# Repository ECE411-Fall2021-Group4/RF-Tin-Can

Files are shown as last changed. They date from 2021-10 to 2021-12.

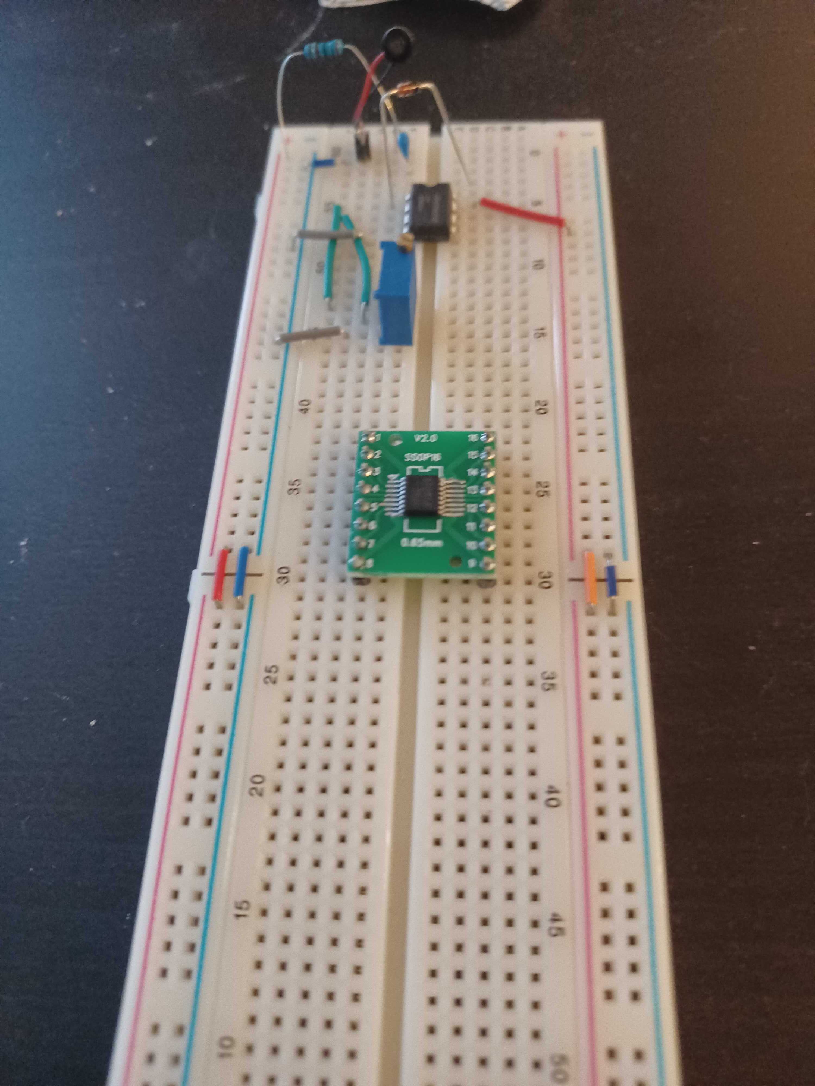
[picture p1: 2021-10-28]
images/Breadboard prototype.jpg

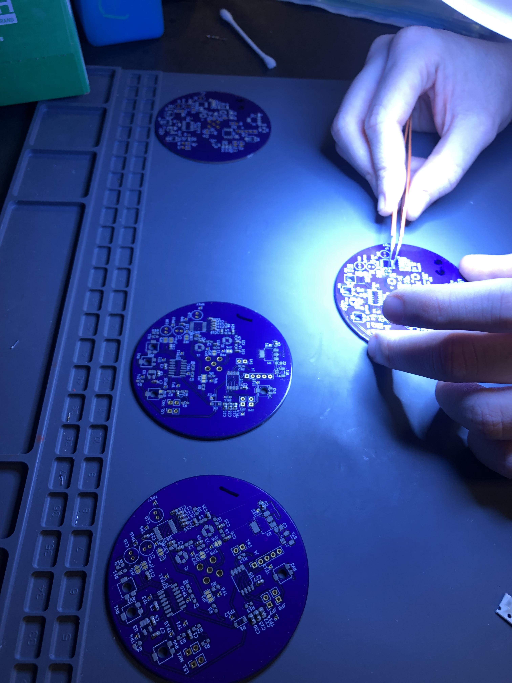
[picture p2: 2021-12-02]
images/IMG_9865.jpeg

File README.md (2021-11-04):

# RF-Tin-Can
LoFi Walkie Talkie aka LoFi Com Can aka jibber jabber Campbell's Can

Mise en place(everything in its place)

File Organization as it pertains to Nick(our sage git master)
1) If a program creates multiple files, only push the ones ones that are needed for others to use the program (i.e. don't push things like log files)
2) If a program has multiple files, create a folder dedicated to them in the correct spot, ask if you're not sure what the spot is (i.e. if projectlibre has a project file and an image/pdf, create a folder in documentation called "Gantt Chart"
3) Do not keep previous revisions, git does that for us. You can tag the commit of the previous version if you feel inspired (i.e. don't have something like schematic_v1, schematic_v2, shematic_v3. It should just have shematic)
4) If you're not sure what to do, ASK

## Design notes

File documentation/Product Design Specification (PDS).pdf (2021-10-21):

David Lay
Sydney McBee
Nick Lekas
Josh Horejs
Garrett Smith
10/20/2021
ECE 411 Product Design Specification

Executive Summary/Concept of Operations
The intended design is to be a two way communications system housed in two tin cans. Each can will have a microphone and speaker for the two users to communicate. The goal is to create an intentionally LoFi two-way communication system to demonstrate the electronics involved in radio frequency systems. This project treats the classic tin cans and a string as a prototype and adds electronic components as its next iterateration.

Brief Market Analysis
This product targets young people with an interest in learning electronics as a novelty. The most likely consumer would be a rural kid with access to a subscription service like Kiwico or similar novelty STEAM oriented learning platforms.

There are similar systems on websites such as www.instructables.com. However, these tutorials do not include all the necessary component pieces as a curated/cohesive system.

The greatest competition is a 5 year old with 2 cans a string and the ability to tie a knot.

Requirements
Must fit all components in a standard #300 size can.
Must have audio send/receive capabilities at either can.
Must use a 2 layer PCB, with an area less than 900cm^2 and no more than 30cm in length. Should use a single cable for signal path between cans
Should automatically cut microphone with audio output is active
Should have mostly surface mount components
May use an antenna instead of a coaxial cable
May have intentional audio distortion circuitry
May have adjustable audio output volume

David Lay
Sydney McBee
Nick Lekas
Josh Horejs
Garrett Smith
10/20/2021
ECE 411 Product Design Specification System Architecture

Below is the level 1 block diagram draft intended for future iteration considerations.

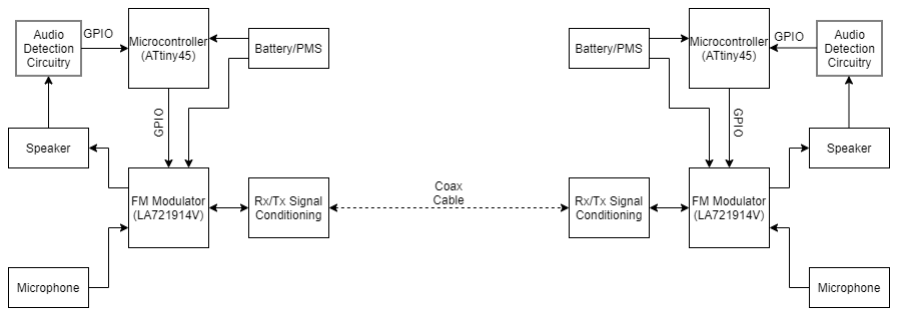
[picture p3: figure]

Design Specification
- Each handheld unit consists of two cans with the same PCB and hardware connected by a coaxial cable
- Sensor: Audio Detection Circuit
- Audio detection circuit transmits a signal to the microcontroller when it senses audio being played on the speaker.
- Audio detection circuitry consists of a rectifier and low pass filter that feeds into a comparator, that then triggers the microcontroller if above a threshold. The specific cutoff will be tuned by adding a gainstage to the filter
- Processor: ATtiny45
- Sends signal to FM Modulator when audio playback is detected on speaker
- Actuator: FM Modulator (LA721914V)
- Cuts microphone when signaled by microcontroller
- Uses filters and a wilkinson combiner for separating frequencies transmitted through coaxial cable
- Rx and Tx frequencies will be set via jumper
- Power: Battery (LiPo or 9V battery) and necessary DC-DC voltage regulators
- Each handheld unit will have an independent battery/power management system
- PMS will not include onboard battery charging

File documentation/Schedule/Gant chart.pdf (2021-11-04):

1 Administrative 20.25 days 10/7/21 3:57 PM 11/5/21 8:57 AM 2 Generate 3 Projects 0.25 days 10/7/21 3:57 PM 10/8/21 8:57 AM Josh;Nick 3 Product design specification(... 0.167 days 10/14/21 3:57 PM 10/15/21 8:17 AM 2 David;Josh;Nick 4 Project schedule 0.5 days 10/28/21 3:57 PM 10/29/21 10:57 AM 3 Josh 5 FunctionalDecomposition 0.25 days 11/4/21 3:57 PM 11/5/21 8:57 AM David;Garrett 8 Circuit 32.125 day... 10/7/21 7:00 AM 11/22/21 9:00 AM 9 Purchase components 0.5 days 10/7/21 7:00 AM 10/7/21 1:00 PM 3 David 10 KiCAD initial circuit 0.5 days 10/7/21 10:57 AM 10/7/21 3:57 PM 3 Sydney 11 Iteration 1 2 days 10/21/21 8:00 AM 10/22/21 5:00 PM 12 Breadboard 2 days 10/21/21 8:00 AM 10/22/21 5:00 PM 9 13 speaker 2 days 10/21/21 8:00 AM 10/22/21 5:00 PM Sydney 14 mic 2 days 10/21/21 8:00 AM 10/22/21 5:00 PM Garrett 15 MC 2 days 10/21/21 8:00 AM 10/22/21 5:00 PM Nick 16 Design Review 2.125 days 11/3/21 8:00 AM 11/5/21 9:00 AM 12 17 criticque 0.125 days 11/3/21 8:00 AM 11/3/21 9:00 AM 12 Josh;Nick;David;Garrett;Sy... 18 Edit & Implementation 2 days 11/3/21 9:00 AM 11/5/21 9:00 AM 17 David;Garrett 19 Preliminary Schematic 1 day? 11/5/21 9:00 AM 11/8/21 9:00 AM 16 Garrett 20 Iteration 2 2.25 days 11/5/21 9:00 AM 11/9/21 11:00 AM 21 Power Budget 0.25 days 11/5/21 9:00 AM 11/5/21 11:00 AM 16 Josh 22 Power Circuit 2 days 11/5/21 11:00 AM 11/9/21 11:00 AM 21 Josh 23 BOM 0.5 days 11/9/21 11:00 AM 11/9/21 4:00 PM 22 Nick 24 Design Review 2 days 11/9/21 11:00 AM 11/11/21 11:00 AM 22 25 critique 0.125 days 11/9/21 11:00 AM 11/9/21 1:00 PM Josh;Nick;David;Garrett;Sy... 26 Edit & Implementation 2 days 11/9/21 11:00 AM 11/11/21 11:00 AM 27 Rough Draft CAD 1 day 11/10/21 9:00 AM 11/11/21 9:00 AM 26 28 Final CAD 1 day 11/11/21 9:00 AM 11/12/21 9:00 AM 27 29 Fab Boards 5 days 11/11/21 9:00 AM 11/18/21 9:00 AM 28 30 Iteration 3 2 days? 11/18/21 9:00 AM 11/22/21 9:00 AM 31 Solder parts 1 day? 11/18/21 9:00 AM 11/19/21 9:00 AM 29 32 UML Modeling 1 day? 11/19/21 9:00 AM 11/22/21 9:00 AM 31 33 Test Plan 1 day? 11/19/21 9:00 AM 11/22/21 9:00 AM 31 36 Presentation 0.062 days? 12/10/21 9:00 AM 12/10/21 9:30 AM 8 Name Duration Start Finish Predec... Resource Names M T W T F S 10 Oct 21 S M T W T F S 17 Oct 21 S M T W T F S 24 Oct 21 S M T W T F S 31 Oct 21 S M T W T F S 7 Nov 21 S M T W T F S 14 Nov 21 S M T W T F S 21 Nov 21 S M T W T F S 28 Nov 21 S M T W T F S 5 Dec 21 S M T W T F S 12 Dec 21 S Josh;Nick David;Josh;Nick Josh David;Garrett David Sydney Sydney Garrett Nick Josh;Nick;David;Garrett;Sydney David;Garrett Garrett Josh Josh Nick Josh;Nick;David;Garrett;Sydney ECE 411 Lofi - page1

12 Dec 21 S M T W T F S 19 Dec 21 S M T W T F S 26 Dec 21 S M T W T F S 2 Jan 22 S M T W T F S 9 Jan 22 S ECE 411 Lofi - page2

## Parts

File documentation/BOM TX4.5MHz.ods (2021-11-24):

Bill Of Materials for Team 4
Last Modified; 2021/11/23
PCB version: 1.0
BOM revision: 1.0
TX: 4.5MHz
Count | RefDes | P/NP | MFG | MPN | Description | Dist | DPN | Cost Ea | Cost Total
1 | BT1 |  |  |  | 9V battery |  |  |  | $0.00
2 | C1, C19 |  |  | CL10A105KO8NNNC | 1 µF ±10% 16V Ceramic Capacitor X5R 0603 (1608 Metric) | Digi-Key | 1276-1034-2-ND | $0.10 | $0.20
1 | C2 |  |  | C1608JB0J226M080AC | 22 µF ±20% 6.3V Ceramic Capacitor JB 0603 (1608 Metric) | Digi-Key | 445-11192-2-ND | $0.40 | $0.40
8 | C3, C7, C9, C11, C12, C15, C16, C27 |  |  | C0603C104K4NACAUTO | 0.1 µF ±10% 16V Ceramic Capacitor X8L 0603 (1608 Metric) | Digi-Key | 399-C0603C104K4NACAUTOTR-ND | $0.13 | $1.04
4 | C4, C20, C22, C23 |  |  | C1608JB0J226M080AC | 22 µF ±20% 6.3V Ceramic Capacitor JB 0603 (1608 Metric) | Digi-Key | 445-11192-2-ND | $0.40 | $1.60
2 | C5, C8 |  |  | C0603C123K5RAC7867 | CAP CER 0.012UF 50V X7R | Digi-Key | 399-C0603C123K5RAC7867TR-ND | $0.10 | $0.20
1 | C6 |  |  | CL10C121JB81PNC | CAP CER 120PF 50V C0G/NP0 | Digi-Key | 1276-2179-2-ND | $0.13 | $0.13
2 | C10, C18 |  |  | 860020672005 | 1 µF 50 V Aluminum Electrolytic Capacitors Radial | Digi-Key | 732-8851-1-ND | $0.10 | $0.20
1 | C13 |  |  | 0603B103K500CT | 10000 pF ±10% 50V Ceramic Capacitor X7R 0603 (1608 Metric) | Digi-Key | 1292-1386-2-ND | $0.10 | $0.10
1 | C14 |  |  | CL10B682JB8NNNC | 6800 pF ±5% 50V Ceramic Capacitor X7R 0603 (1608 Metric) | Digi-Key | 1276-2099-2-ND | $0.10 | $0.10
1 | C17 |  |  | 860010672004 | 0.47 µF 50 V Aluminum Electrolytic Capacitors Radial | Digi-Key | 732-8656-1-ND | $0.11 | $0.11
2 | C21, C26 |  |  | CL10B471KB8NNNC | CAP CER 470PF 50V X7R | Digi-Key | 1276-1094-2-ND | $0.10 | $0.20
2 | C24, C25 |  |  | CL10B102KB8NNNC | CAP CER 1000PF 50V X7R | Digi-Key | 1276-1018-2-ND | $0.10 | $0.20
1 | D1 |  |  | MBR0580S1-7 | Diode Schottky 80 V 500mA Surface Mount SOD-123 | Digi-Key | MBR0580S1-7DITR-ND | $0.32 | $0.32
2 | J1, J3 |  |  | 734120110 | CONN UMC RCPT STR 50 OHM SMD | Digi-Key | WM5587TR-ND | $0.77 | $1.54
1 | J2 |  |  | 132134 | CONN SMA JACK STR 50 OHM PCB | Digi-Key | ACX1230-ND | $5.27 | $5.27
1 | J4 |  |  | PH1-04-UA | CONN HEADER VERT 4POS | Digi-Key | 2057-PH1-04-UA-ND | $0.10 | $0.10
1 | JP7, JP8 |  |  | 61300211121 | Connector Header Through Hole 2 position 0.100" | Digi-Key | 732-5315-ND | $0.13 | $0.13
2 | L1, L3 |  |  | LQW18AN47NJ00D | FIXED IND 47NH 380MA 290MOHM | Digi-Key | 490-6895-2-ND | $0.16 | $0.32
1 | L2 |  |  | LQM18PN4R7MFRL | FIXED IND 4.7UH 620MA 550MOHM | Digi-Key | 490-12065-2-ND | $0.24 | $0.24
3 | L4, L5, L6 |  |  | LQM18PN3R3MFRL | FIXED IND 3.3UH 700MA 438MOHM | Digi-Key | 490-12783-2-ND | $0.24 | $0.72
1 | LS1 |  |  | 1890 | Adafruit Accessories Mini Metal Speaker w/ Wires - 8 ohm 0.5W | Mouser | 485-1890 | $1.95 | $1.95
1 | MK1 |  |  | CMEJ-4618-42-L015 | Microphones 4.6 mm, Omnidirectional, Wire Leads, 2.0 Vdc, Elecret Condenser Microphone | Mouser | 490-CMEJ-4618-42L015 | $0.55 | $0.55
1 | R1 |  |  | RT0603FRE132K2L | 2.2 kOhms ±1% 0.1W, 1/10W Chip Resistor 0603 (1608 Metric) - Thin Film | Digi-Key | 13-RT0603FRE132K2LTR-ND | $0.10 | $0.10
11 | R2, R3, R4, R5, R6, R7, R8, R10, R11, R12, R13 |  |  | RT0603FRE132K2L | 2.2 kOhms ±1% 0.1W, 1/10W Chip Resistor 0603 (1608 Metric) - Thin Film | Digi-Key | 13-RT0603FRE132K2LTR-ND | $0.10 | $1.10
1 | R9 |  |  | RT0603FRE132K2L | 2.2 kOhms ±1% 0.1W, 1/10W Chip Resistor 0603 (1608 Metric) - Thin Film | Digi-Key | 13-RT0603FRE132K2LTR-ND | $0.10 | $0.10
4 | RV1, RV2, RV3, RV4 |  |  | 3361P-1-104GLF | 100 kOhms 0.5W, 1/2W Gull Wing Surface Mount Trimmer Potentiometer Cermet 1.0 Turn Top Adjustment | Digi-Key | 3314R-1-104ETR-ND | $1.26 | $5.04
1 | SW1 |  |  |  |  |  |  |  | $0.00
1 | U1 |  |  | LM2937IMP-5.0 | Linear Voltage Regulator IC Positive Fixed 1 Output 400mA | Digi-Key | LM2937IMP-5.0TR-ND | $3.25 | $3.25
1 | U2 |  |  | MCP6L04T-E/ST | IC OPAMP GP 4 CIRCUIT | Digi-Key | MCP6L04T-E/STTR-ND | $0.46 | $0.46
1 | U3 |  |  | 74HC4053PW,118 | IC MUX/DEMUX TRIPLE 2X1 | Digi-Key | 1727-4014-2-ND | $0.51 | $0.51
1 | U4 |  |  | LA72914V-TLM-H | Modulator / Demodulator FM MODULATOR DEMODULATOR | Mouser | 863-LA72914V-TLM-H | $7.01 | $7.01
1 | U5 |  |  | ATTINY85-20SUR | 8-bit Microcontrollers - MCU AVR 8KB FLSH 512B EE 512B SRAM-20MHz 5V | Mouser | 556-ATTINY85-20SUR | $1.43 | $1.43

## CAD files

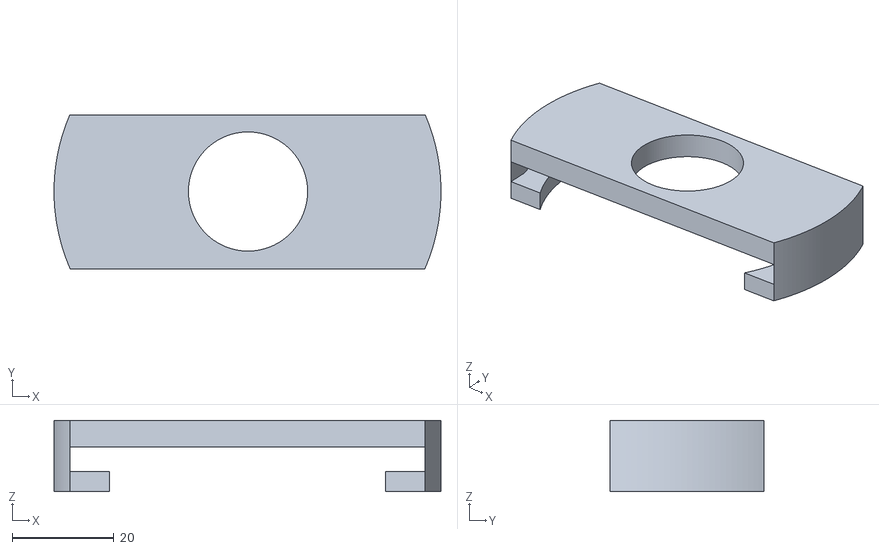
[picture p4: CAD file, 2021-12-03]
3D Print/Version1.stl
76.0 x 30.2 x 14.0

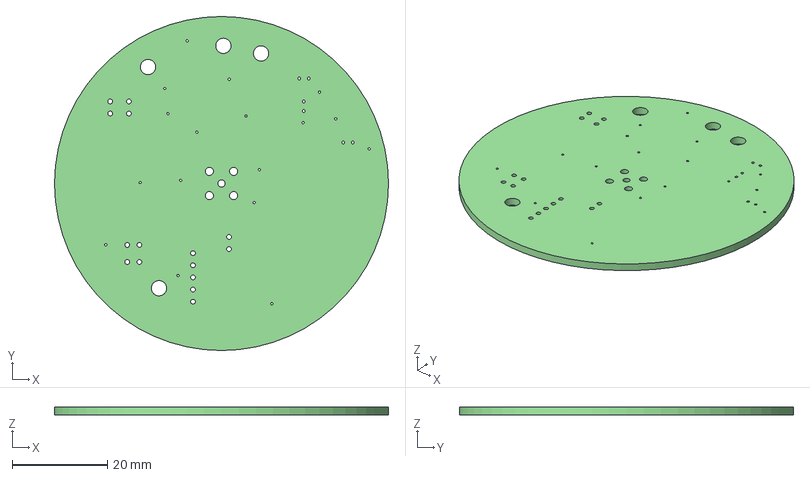
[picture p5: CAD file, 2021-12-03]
KiCAD/411_1.step
70.0 x 70.0 x 1.60 mm

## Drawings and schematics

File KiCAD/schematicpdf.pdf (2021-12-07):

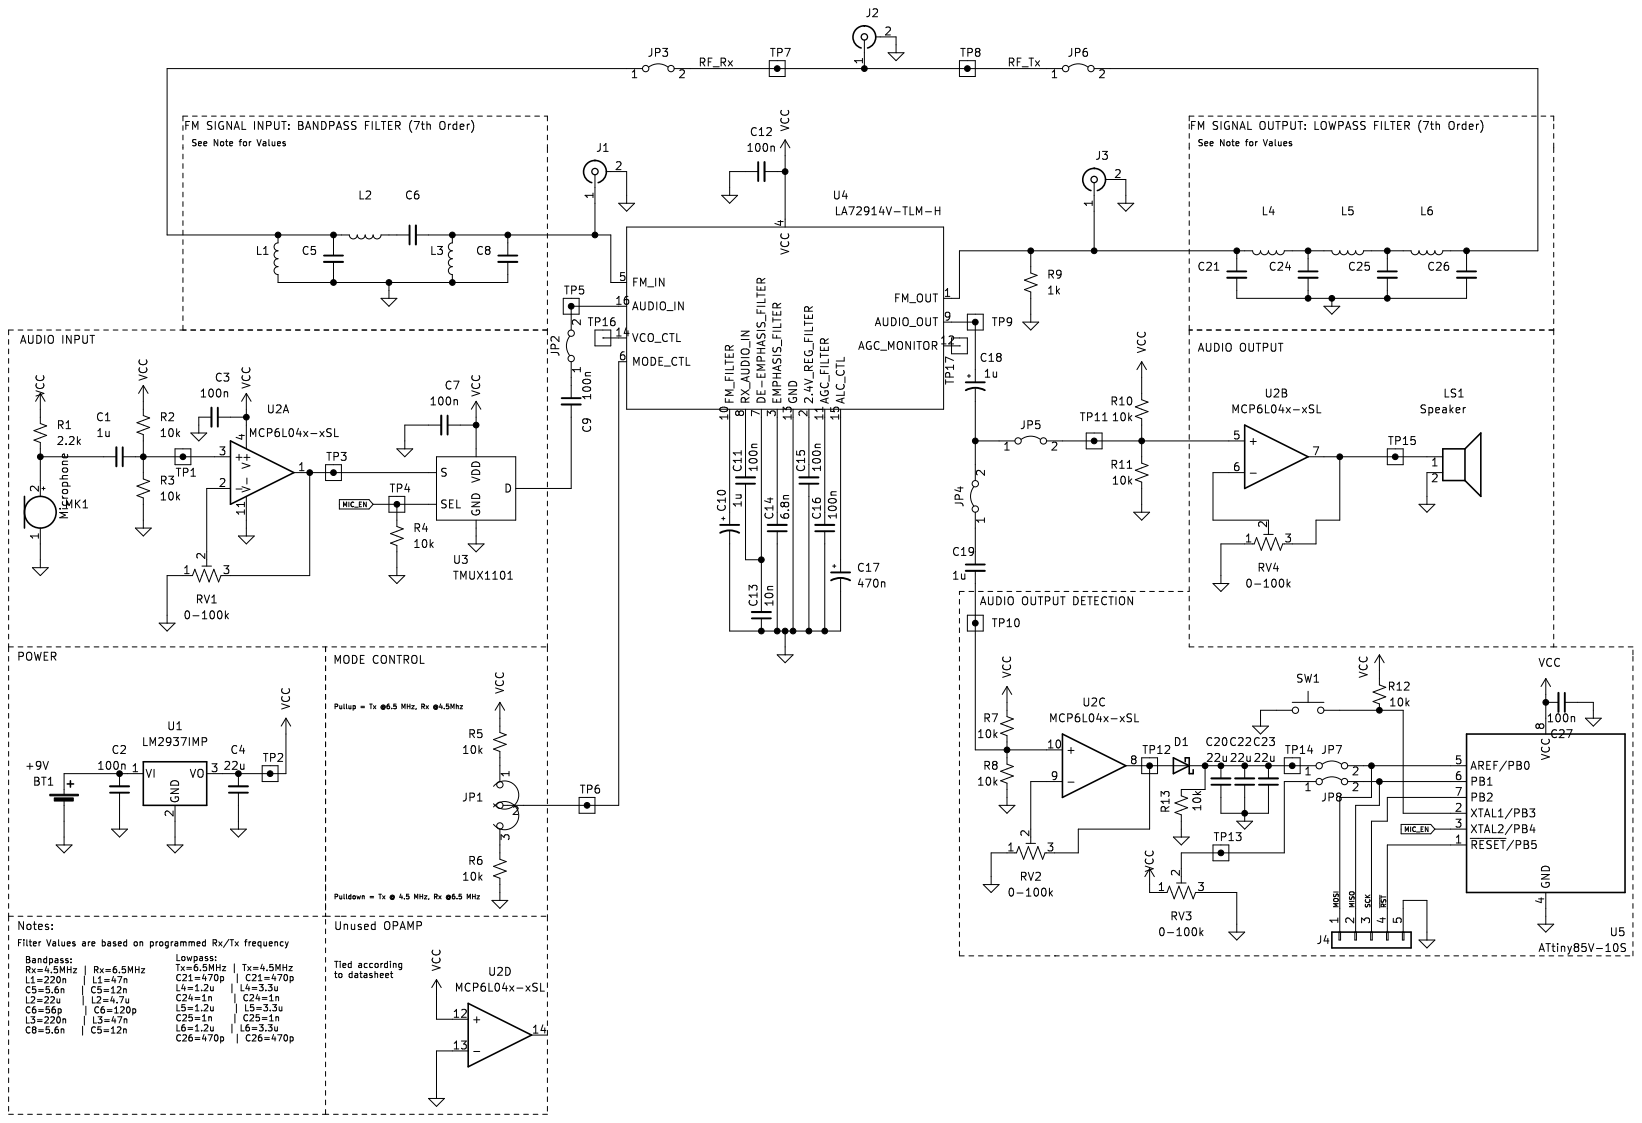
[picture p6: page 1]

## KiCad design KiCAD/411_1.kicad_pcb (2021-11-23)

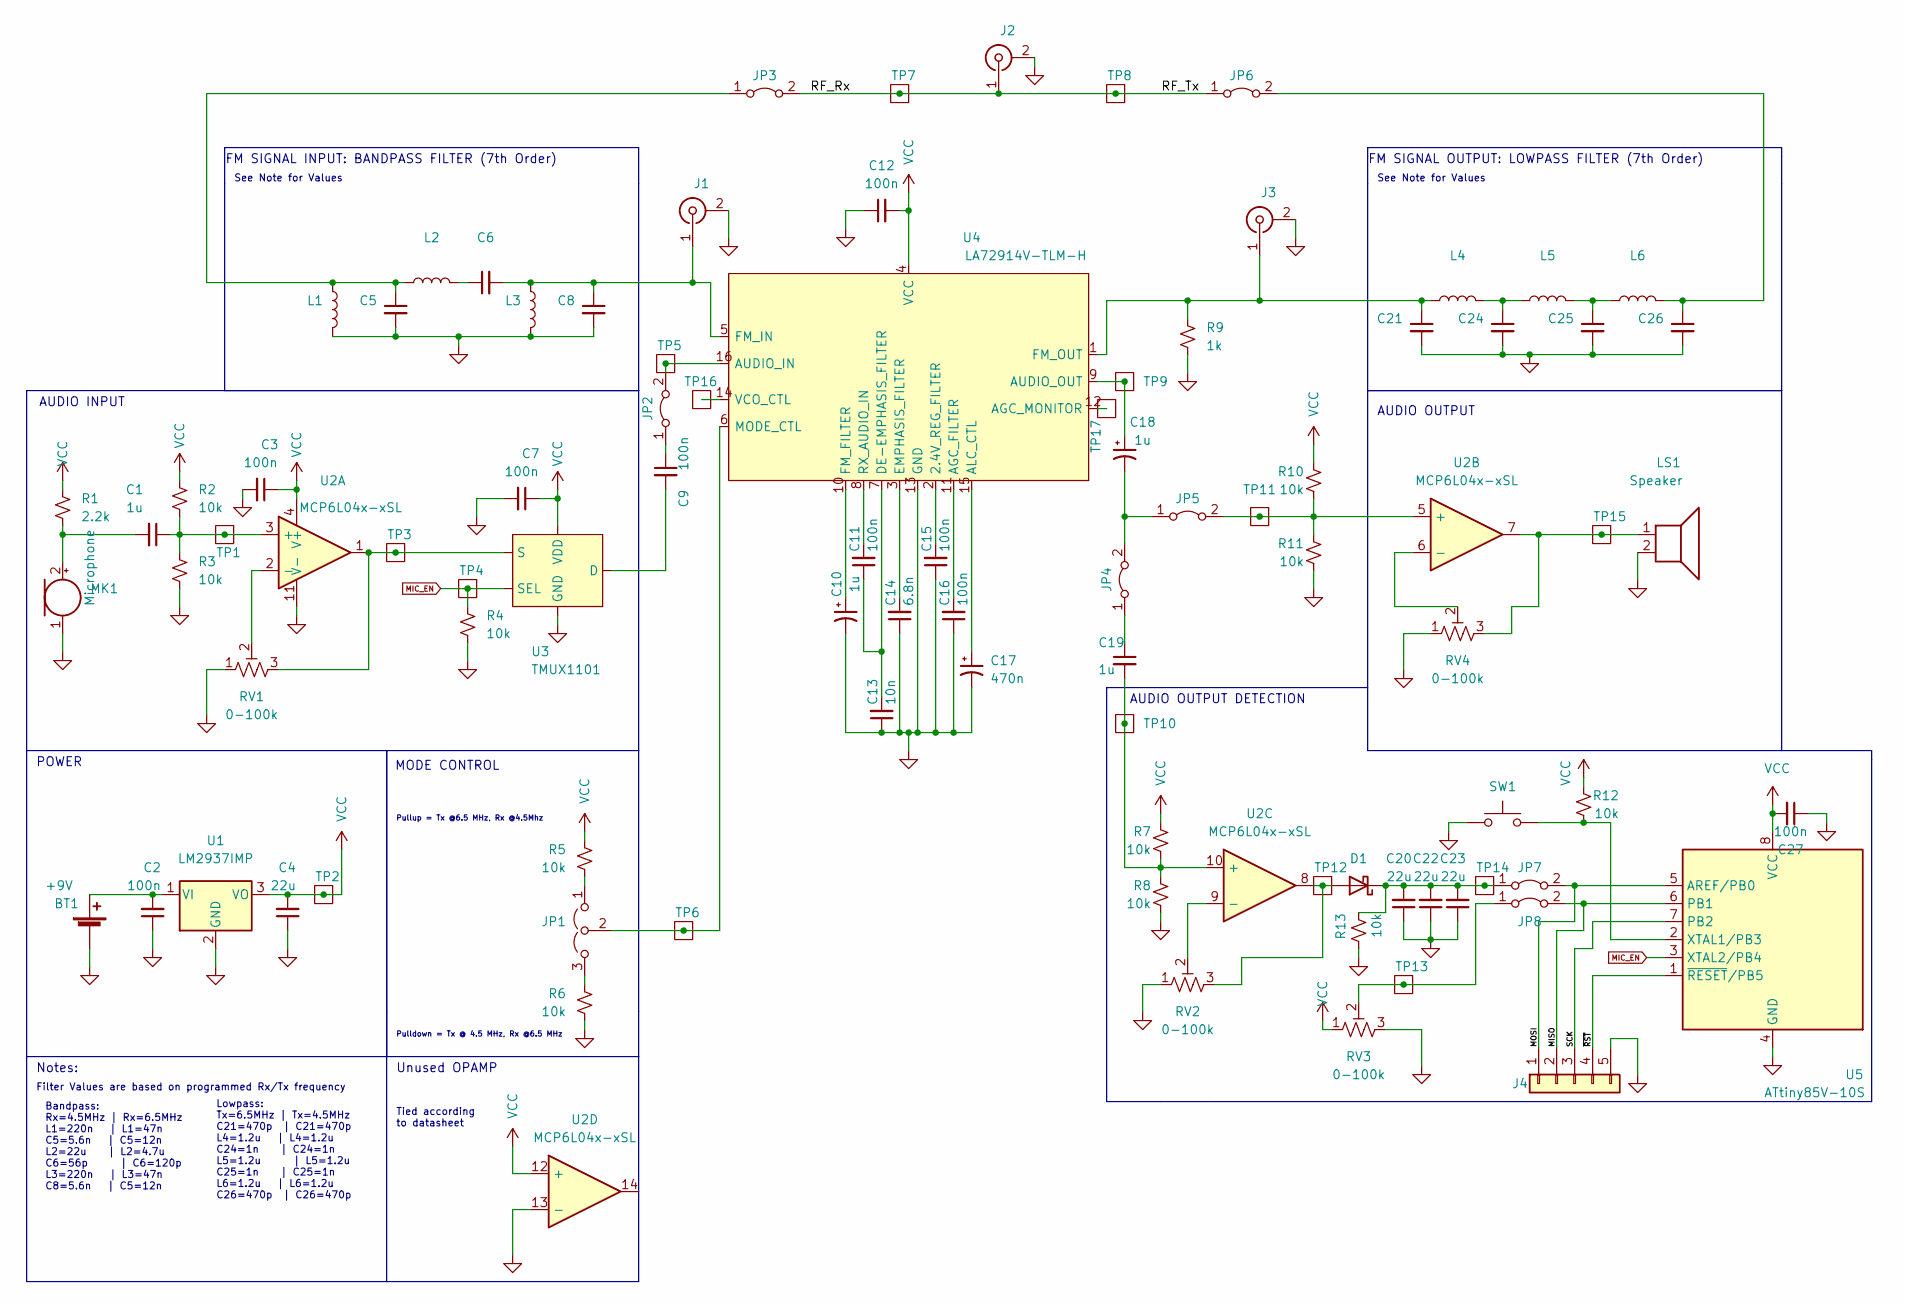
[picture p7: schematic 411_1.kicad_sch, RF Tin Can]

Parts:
BT1: +9V; JST_SH_BM02B-SRSS-TB_1x02-1MP_P1.00mm_Vertical
C1, C19: 1u; C_0603_1608Metric_Pad1.08x0.95mm_HandSolder; MPN CL10A105KO8NNNC
C2: 100n; C_0805_2012Metric_Pad1.18x1.45mm_HandSolder; MPN C1608JB0J226M080AC
C3, C7, C9, C11, C12, C15, C16, C27: 100n; C_0603_1608Metric_Pad1.08x0.95mm_HandSolder; MPN C0603C104K4NACAUTO
C4, C20, C22, C23: 22u; C_0805_2012Metric_Pad1.18x1.45mm_HandSolder; MPN C1608JB0J226M080AC
C5, C6, C8: 5.6n; C_0603_1608Metric_Pad1.08x0.95mm_HandSolder; MPN 06035C562KAT2A
C10, C18: 1u; C_Radial_D5.0mm_H5.0mm_P2.00mm; MPN 860020672005
C13: 10n; C_0603_1608Metric_Pad1.08x0.95mm_HandSolder; MPN 0603B103K500CT
C14: 6.8n; C_0603_1608Metric_Pad1.08x0.95mm_HandSolder; MPN CL10B682JB8NNNC
C17: 470n; C_Radial_D5.0mm_H5.0mm_P2.00mm; MPN 860010672004
C21, C24, C25, C26: 470p; C_0603_1608Metric_Pad1.08x0.95mm_HandSolder; MPN CL10B471KB8NNNC
D1: D_Schottky; D_SOD-123; MPN MBR0580S1-7
J1, J3: Conn_Coaxial; U.FL_Molex_MCRF_73412-0110_Vertical; MPN 0734120110
J2: Conn_Coaxial; SMA_Amphenol_132134_Vertical; MPN 132134
J4: Conn_01x05; PinSocket_1x05_P2.54mm_Vertical
JP1: Jumper_3_Open; SolderJumper-3_P1.3mm_Open_Pad1.0x1.5mm; MPN 2011-1X03G00SC028B
JP2, JP3, JP4, JP5, JP6: Jumper; SolderJumper-2_P1.3mm_Open_RoundedPad1.0x1.5mm
JP7: Connector_PinHeader_1.00mm:PinHeader_1x02_P1.00mm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; PinSocket_1x02_P2.54mm_Vertical
JP8: Jumper_2_Bridged; PinSocket_1x02_P2.54mm_Vertical
L1, L2, L3: 220n; C_0603_1608Metric_Pad1.08x0.95mm_HandSolder; MPN 0603DC-R22XJRW
L4, L5, L6: 3.3u; C_0603_1608Metric_Pad1.08x0.95mm_HandSolder; MPN CWF1610-3R3K
LS1: Speaker; PinSocket_1x02_P2.54mm_Vertical; MPN 1890
MK1: Microphone; PinSocket_1x02_P2.54mm_Vertical; MPN CMEJ-4618-42-L015
R1: 2.2k; R_0603_1608Metric_Pad0.98x0.95mm_HandSolder; MPN RT0603FRE132K2L
R2, R3, R4, R5, R6, R7, R8, R10, R11, R12, R13: 10k; R_0603_1608Metric_Pad0.98x0.95mm_HandSolder; MPN RT0603FRE132K2L
R9: 1k; R_0603_1608Metric_Pad0.98x0.95mm_HandSolder; MPN RT0603FRE132K2L
RV1, RV2, RV3, RV4: 0-100k; Potentiometer_Bourns_3314R-1_Vertical_Hole; MPN 3361P-1-104GLF
SW1: SW_Push; PinSocket_1x02_P2.54mm_Vertical
TP1, TP2, TP3, TP4, TP5, TP6, TP7, TP8, TP9, TP10, TP11, TP12, TP13, TP14, TP15, TP16, TP17: Testpoint; PinHeader_1x01_P1.00mm_Vertical
U1: LM2937IMP; SOT-223-3_TabPin2; MPN LM2937IMP-5.0
U2: MCP6L04x-xSL; SOIC-14_3.9x8.7mm_P1.27mm
U3: TMUX1101; SOT-23-5_HandSoldering; MPN 74HC4053PW,118
U4: LA72914V-TLM-H; TSSOP-16_4.4x5mm_P0.65mm; MPN LA72914V-TLM-H
U5: ATtiny85V-10S; SOIC-8W_5.3x5.3mm_P1.27mm; MPN ATTINY85-20SUR

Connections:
/MISO: J4.2, JP8.2 (B), U5.6 (PB1)
/MOSI: J4.1, JP7.2 (B), U5.5 (AREF/PB0)
/RF_Rx: J2.1 (In), JP3.2 (B), JP6.1 (A), TP7.1, TP8.1
/SCK: J4.3, U5.7 (PB2)
/~RST: J4.4, U5.1 (~RESET/PB5)
GND: BT1.2 (-), C2.1, C3.2, C4.1, C5.2, C7.2, C8.2, C10.2, C12.1, C13.1, C14.1, C15.1, C16.1, C17.2, C20.1, C21.2, C22.1, C23.1, C24.2, C25.2, C26.2, C27.1, J1.2 (Ext), J2.2 (Ext), J3.2 (Ext), J4.5, L1.1, L3.1, LS1.2, MK1.1 (-), R3.1, R4.1, R6.2, R8.2, R9.1, R11.2, R13.2, RV1.1, RV2.1, RV3.3, RV4.1, SW1.1, U1.2 (GND), U2.11 (V-), U2.13 (-), U3.3 (GND), U4.13 (GND), U5.4 (GND)
MIC_EN: R4.2, TP4.1, U3.4 (SEL), U5.3 (XTAL2/PB4)
unnamed: BT1.1 (+), C2.2, U1.1 (VI)
unnamed: C1.1, R2.1, R3.2, TP1.1, U2.3 (+)
unnamed: C1.2, MK1.2 (+), R1.1
unnamed: C5.1, JP3.1 (A), L1.2, L2.2
unnamed: C6.1, L2.1
unnamed: C6.2, C8.1, J1.1 (In), L3.2, U4.5 (FM_IN)
unnamed: C9.1, JP2.1 (A)
unnamed: C9.2, U3.1 (D)
unnamed: C11.1, C13.2, U4.7 (DE-EMPHASIS_FILTER)
unnamed: C11.2, U4.8 (RX_AUDIO_IN)
unnamed: C14.2, U4.3 (EMPHASIS_FILTER)
unnamed: C15.2, U4.2 (2.4V_REG_FILTER)
unnamed: C16.2, U4.11 (AGC_FILTER)
unnamed: C17.1, U4.15 (ALC_CTL)
unnamed: C19.1, JP4.1 (A)
unnamed: C19.2, R7.2, R8.1, TP10.1, U2.10 (+)
unnamed: C20.2, C22.2, C23.2, D1.1 (K), JP7.1 (A), R13.1, TP14.1
unnamed: C21.1, J3.1 (In), L4.2, R9.2, U4.1 (FM_OUT)
unnamed: C24.1, L4.1, L5.2
unnamed: C25.1, L5.1, L6.2
unnamed: C26.1, JP6.2 (B), L6.1
unnamed: D1.2 (A), RV2.3, TP12.1, U2.8
unnamed: JP1.1 (A), R5.2
unnamed: JP1.2 (C), TP6.1, U4.6 (MODE_CTL)
unnamed: JP1.3 (B), R6.1
unnamed: JP2.2 (B), TP5.1, U4.16 (AUDIO_IN)
unnamed: C18.2, JP4.2 (B), JP5.1 (A)
unnamed: JP5.2 (B), R10.2, R11.1, TP11.1, U2.5 (+)
unnamed: JP8.1 (A), RV3.2, TP13.1
unnamed: LS1.1, RV4.3, TP15.1, U2.7
unnamed: R12.2, SW1.2, U5.2 (XTAL1/PB3)
unnamed: RV1.2, U2.2 (-)
unnamed: RV1.3, TP3.1, U2.1, U3.2 (S)
unnamed: RV2.2, U2.9 (-)
unnamed: RV4.2, U2.6 (-)
unnamed: C18.1, TP9.1, U4.9 (AUDIO_OUT)
unnamed: TP16.1, U4.14 (VCO_CTL)
unnamed: TP17.1, U4.12 (AGC_MONITOR)
unnamed: C10.1, U4.10 (FM_FILTER)
VCC: C3.1, C4.2, C7.1, C12.2, C27.2, R1.2, R2.2, R5.1, R7.1, R10.1, R12.1, RV3.1, TP2.1, U1.3 (VO), U2.4 (V+), U2.12 (+), U3.5 (VDD), U4.4 (VCC), U5.8 (VCC)

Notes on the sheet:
POWER
Notes:
Filter Values are based on programmed Rx/Tx frequency
Bandpass: Rx=4.5MHz | Rx=6.5MHz L1=220n | L1=47n C5=5.6n | C5=12n L2=22u | L2=4.7u C6=56p | C6=120p L3=220n | L3=47n C8=5.6n | C5=12n
AUDIO INPUT
Lowpass: Tx=6.5MHz | Tx=4.5MHz C21=470p | C21=470p L4=1.2u | L4=1.2u C24=1n | C24=1n L5=1.2u | L5=1.2u C25=1n | C25=1n L6=1.2u | L6=1.2u C26=470p | C26=470p
See Note for Values
Pullup = Tx @6.5 MHz, Rx @4.5Mhz
Pulldown = Tx @ 4.5 MHz, Rx @6.5 MHz
Unused OPAMP
Tied according to datasheet
MODE CONTROL
FM SIGNAL INPUT: BANDPASS FILTER (7th Order)
AUDIO OUTPUT DETECTION
FM SIGNAL OUTPUT: LOWPASS FILTER (7th Order)
AUDIO OUTPUT

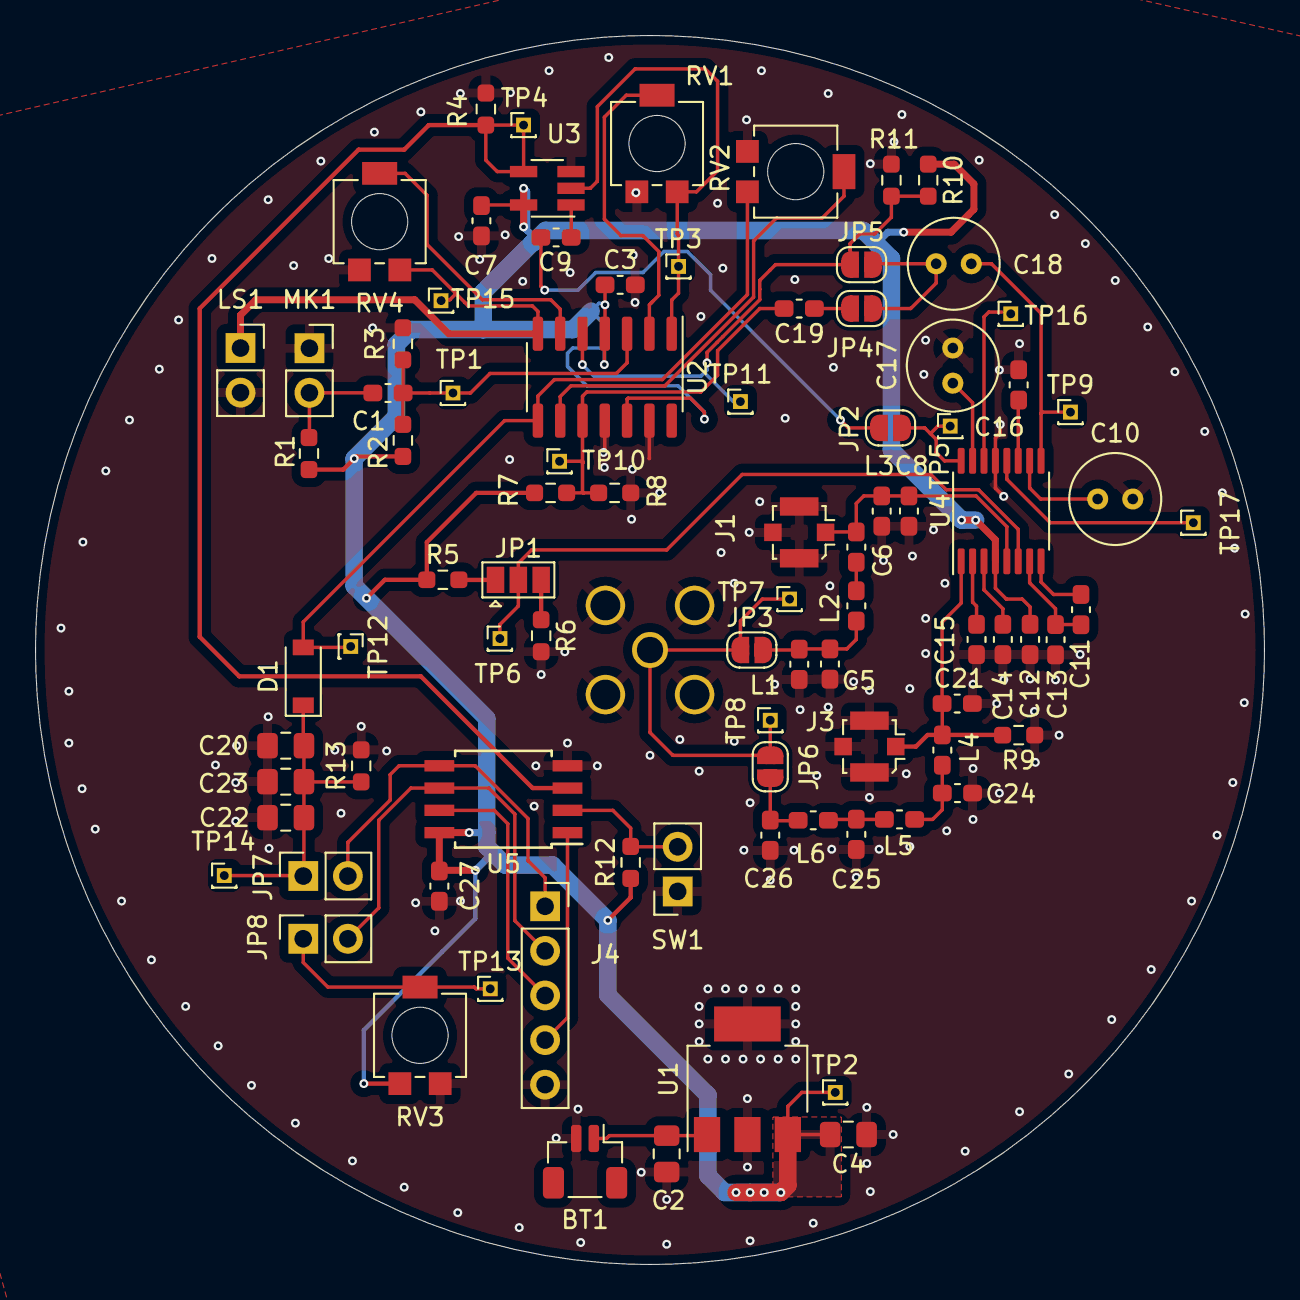
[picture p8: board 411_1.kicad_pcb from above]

Board: 2 copper layers, 70.0 x 70.0 mm, 89 parts (1 on the bottom side), 47 nets.

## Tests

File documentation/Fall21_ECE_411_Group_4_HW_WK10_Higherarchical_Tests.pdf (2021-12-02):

## Unit Test

Test Author: Josh Horejs
Test Case Name: | LA72914 unit Test #1 | Test ID #: | TC-MT-1.1
Description: | Test modem(LA72914V) for power draw and signal input to output integrity. This determines if the IC is faulty. | Type: | x white box □ black box □ ________

Tester Information
| Name of Tester: | | Date:
| Hardware Version: | 1.0 | Time:
| Setup: | Connect 5V DC supply at TP2. Use function generator to apply the 1kHz signal. Connect oscilloscope to pin 9.
S T E P | Action | Expected Result | P A S S | F A I L | N / A | Comments
1 | Power from pin 4 to 13 | Should draw approximately 300 mW
2 | Apply 1kHz input to TP 5 | 1kHz output signal at J3
3 | Apply 1kHz input to J1 | 1kHz output signal at TP9
| Overall test result:

Test Author: Nick Lekas, Garrett Smith

Test Case Name: | Filter test | Test ID #: | 2
Description: | Test the individual lowpass and bandpass filter performance. | Type: | □ white box X black box □ _____________

Tester Information

| Name of Tester: | | Date:
| Hardware Version: | 1.0 | Time:
| Setup: | Disconnect the lowpass filter and connect the bandpass filter. Connect CH1 of the VNA to J1 and CH2 to J2. Run test 1. Disconnect the bandpass filter and connect the lowpass filter. Connect CH1 of the VNA to J3 and CH2 to J2. Run test 2.
T E S T | INPUTS | EXPECTED OUTPUTS | P A S S | F A I L | N / A | Comments
1 | Frequency sweep from 1Hz to 10MHz | Tx 4.5MHz: Bandpass center frequency at 4.5MHz+/-250kHz with -6db+/-3db gain Tx 6.5MHz: Bandpass center frequency at 6.5MHz+/-250kHz with -9db+/-3db gain
2 | Frequency sweep from 1Hz to 10MHz | Tx 4.5MHz: Lowpass corner frequency at 4.5MHz+/-250kHz with -7db+/-3db gain Tx 6.5MHz: Lowpass corner frequency at 6.5MHz+/-250kHz with -6db+/-3db gain
| Overall test result:

Test Author: David Lay

Test Case Name: | Audio Detection Test | Test ID #: | 3
Description: | Tests the audio detection circuitry and verifies the ATTinys ability to cut the microphone input | Type: | X white box □ black box □ _____________

Tester Information

| Name of Tester: | David Lay | Date:
| HW/SW Version: | 1.0 | Time:
| Setup: | Two cans, a previously validated working can (‘external can’) and the unit under test (UUT) can. Both cans should have previously had the audio signal path and rf signal path validated.
T E S T | INPUTS | EXPECTED OUTPUTS | P A S S | F A I L | N / A | Comments
1 | 1 kHz 1VP-P sine wave into TP10. RV2 may need to be adjusted for gain on the amplifier. Rectification filter also be adjusted by replacing C20, 22, or 23 | DC output on TP14 of at least +1 V with < 5 mVP-P ripple.
2 | 1 kHz 1VP-P sine wave into TP10. RV3 may need to be adjusted for comparator bias voltage. | Logic low on TP14.

3 | 1 kHz 1VP-P sine wave into TP10, and audio input from microphone. | No signal measured from microphone on TP5.
4 | Audio input on external can connected via coax, and audio input from microphone on UUT can. Both external can and UUT can should have audio signal path and RF signal path tested previosuly | The audio input on UUT will not propagate to TP5.
| Overall test result:

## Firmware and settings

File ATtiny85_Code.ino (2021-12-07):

/* TinyTone for ATtiny85 */ 
// To settup ATtiny85 for Arduino IDE follow either: 
//  a. https://makersportal.com/blog/2018/5/19/attiny85-arduino-board-how-to-flash-the-arduino-bootloader-and-run-a-simple-sketch
//  b. https://create.arduino.cc/projecthub/arjun/programming-attiny85-with-arduino-uno-afb829


// Bellow code uses either 1MHz or 8MHz clocks to generate tones initialized by an audio detection sensor.
// Copied from code on https://www.instructables.com/Play-a-Tune-From-ATTINY85-When-Motion-Detected/

int speaker = 1;   // SPEKER PIN 
int sensor  = 2;   // Analog In Pin 2
int state   = LOW;  
int val     = 0;   // variable to store the sensor status 

void setup(){
  // Using Arduino IDE for setting IO pins on ATtiny85
  pinMode(speaker, OUTPUT); // designates output pin 
  pinMode(sensor, INPUT);   // Initialize sensor as an input
  delay(20000);             // Delay before innitializing 
}

void loop(){
  val = digitalRead(sensor);   
  if (val == HIGH) { // Audio in
    playTune();
  }
  delay(2000);
}



// From this point on is irrelevant to our ECE 411 practicum project.
void TinyTone(unsigned char divisor, unsigned char octave, unsigned long duration){
  /*
  TCCR1 = 0x90 | (8 -octave); // for 1MHz clock
  */
  TCCR1 = 0x90 | (11-octave); // for 8MHz clock
  OCR1C = divisor-1;          // set the OCR
  delay(duration);
  TCCR1 = 0x90;               // stop the counter
}


 
// Audio output frequency spectrum. 
const int Note_BM = 247;
const int Note_C  = 240;
const int Note_CS = 225;
const int Note_D  = 213;
const int Note_DS = 201;
const int Note_E  = 190;
const int Note_F  = 179;
const int Note_FS = 169;
const int Note_G  = 159;
const int Note_GS = 150;
const int Note_A  = 142;
const int Note_AS = 134;
const int Note_B  = 127;
const int Note_Cm  = 120;
const int Note_CSm = 113;
const int Note_Dm  = 106;
const int Note_DSm = 99;
const int Note_Em  = 92;
const int Note_Fm  = 85;
const int Note_FSm = 78;
const int Note_Gm  = 71;
const int Note_GSm = 64;
const int Note_Am  = 57;
const int Note_ASm = 50;
const int Note_Bm  = 43;

int scale = 800; // This is the rythm for audio output. 

// Song: White Stripes, Seven Nation Army rythm. (the tone scale is not finished)
void playTune(void)
{
  
  //a minuet tune -  this section may be changed
 TinyTone(Note_E, 4, scale);
 delay(scale/8);
 TinyTone(Note_E, 4, scale/4);
 delay(scale/6);
 TinyTone(Note_G, 4, scale/4);
 delay(scale/6);
 TinyTone(Note_E, 4, scale/4);
 delay(scale/6);
 TinyTone(Note_D, 4, scale/4);
 delay(scale/6);
 TinyTone(Note_C, 4, scale*1.75);
 delay(scale/6);
 TinyTone(Note_BM, 4, scale);
 delay(scale);

 
 TinyTone(Note_E, 4, scale);
 delay(scale/8);
 TinyTone(Note_E, 4, scale/4);
 delay(scale/6);
 TinyTone(Note_G, 4, scale/4);
 delay(scale/6);
 TinyTone(Note_E, 4, scale/4);
 delay(scale/6);
 TinyTone(Note_D, 4, scale/4);
 delay(scale/6);
 TinyTone(Note_C, 4, scale*2);
 delay(scale/6);
 TinyTone(Note_BM, 4, scale);
 delay(scale);

  
 TinyTone(Note_E, 4, scale*1.5);
 delay(scale/8);
 TinyTone(Note_E, 4, scale/4);
 delay(scale/6);
 TinyTone(Note_G, 4, scale/4);
 delay(scale/6);
 TinyTone(Note_E, 4, scale/4);
 delay(scale/6);
 TinyTone(Note_D, 4, scale/4);
 delay(scale/6);
 TinyTone(Note_C, 4, scale);
 delay(scale/6);
 TinyTone(Note_D, 4, scale/4);
 delay(scale/6);
 TinyTone(Note_C, 4, scale/4);
 delay(scale/6);
 TinyTone(Note_BM, 4, scale);
 delay(scale);
}

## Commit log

2021-10-28 Create Breadboard prototype.jpg
2021-11-03 organized repo
    [411_0.sch, 411_1.sch]
2021-11-03 Added BPF
    [411_0.sch, 411_1.kicad_sch, 411_1.sch]
2021-11-04 Updated schematic with all of the things. Started preliminary layout
    [411_1.kicad_pcb, 411_1.kicad_sch]
2021-11-07 added BOM for week 7
    [BOM_Team4.xlsx]
2021-11-07 deleted BOM :(
    [BOM_Team4.xlsx]
2021-11-10 Add files via upload
    Added two IO Signal filters, Mode Control jumper for 6.5MHz=Vcc, 4.5MHz=GND
    [411_1.kicad_sch]
2021-11-18 Rev 1.0 shipped to oshpark
    [411_1.kicad_pcb, 411_1.kicad_sch]
2021-11-23 Added info to components for bom generation
    [411_1.kicad_pcb, 411_1.kicad_sch]
2021-11-24 Fixed look up values for filter values
    [411_1.kicad_sch]
2021-11-24 generated BOMS for both boards
    [BOM TX4.5MHz.ods, BOM TX6.5MHz.ods]
2021-12-03 Added 3D print STL
    Added 3D print STL
    [411_1.step, Version1.stl]
2021-12-07 Printed schematic pdf
